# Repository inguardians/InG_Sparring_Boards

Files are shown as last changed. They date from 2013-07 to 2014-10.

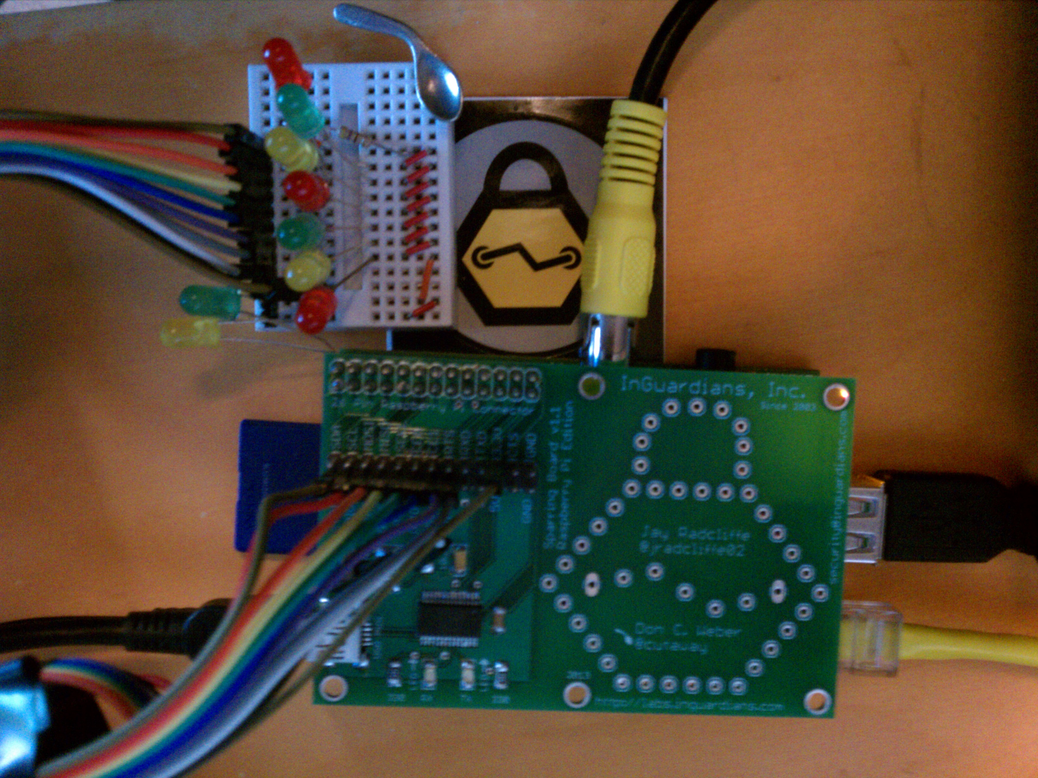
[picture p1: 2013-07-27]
trunk/version_1_pi/images/InG_version1_pi_led_testing_0.jpg

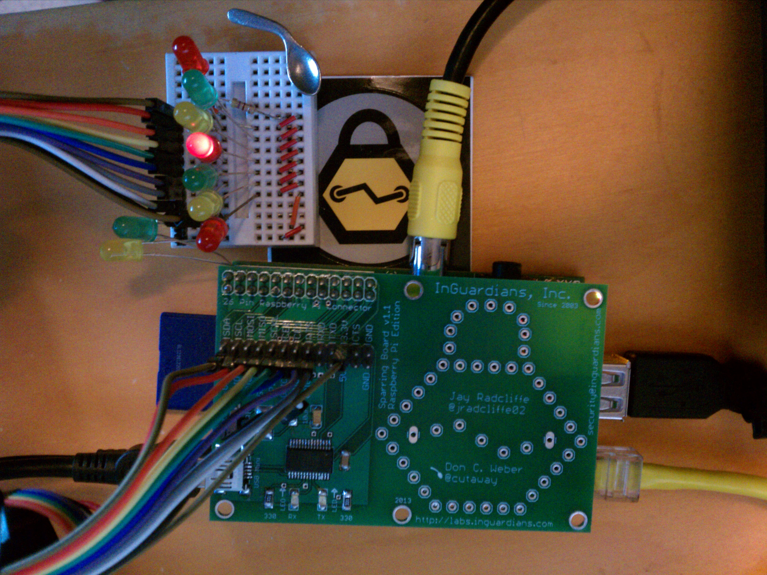
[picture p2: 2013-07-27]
trunk/version_1_pi/images/InG_version1_pi_led_testing_3.jpg

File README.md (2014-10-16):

InG_Sparring_Boards
===================

InGuardians Sparring Boards - a collection of printed circuit boards (PCB) to help users learn about embedded devices and the tools and techniques used during development and assessment.

InGuardians<br>
http://www.inguardians.com<br>
http://labs.inguardians.com<br>

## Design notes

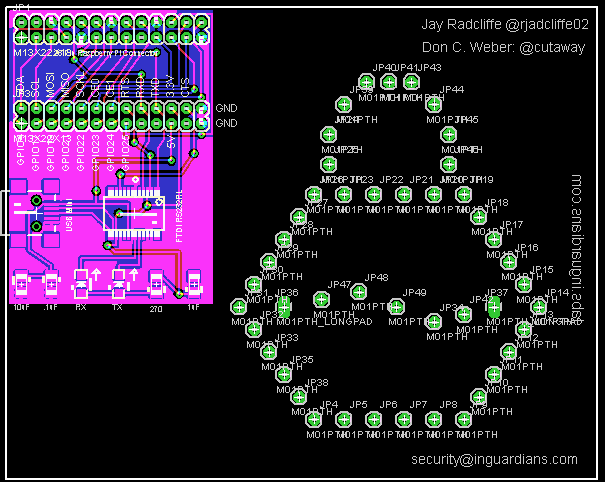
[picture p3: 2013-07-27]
trunk/version_1_pi/design/eagle/ing_dc2013_board.png

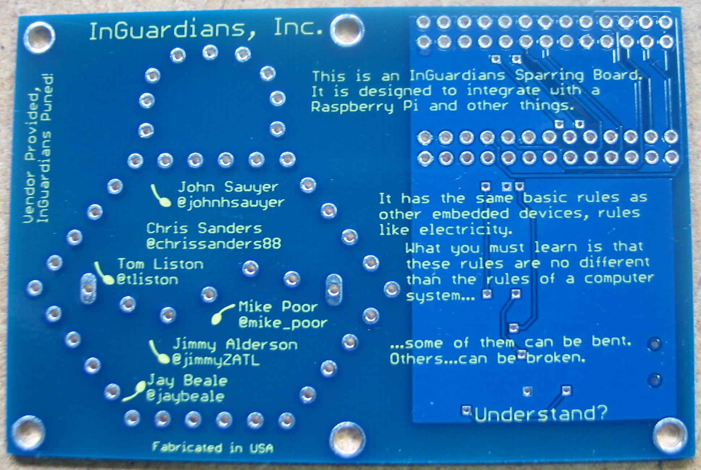
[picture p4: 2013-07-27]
trunk/version_1_pi/images/InG_version1_pi_back.JPG

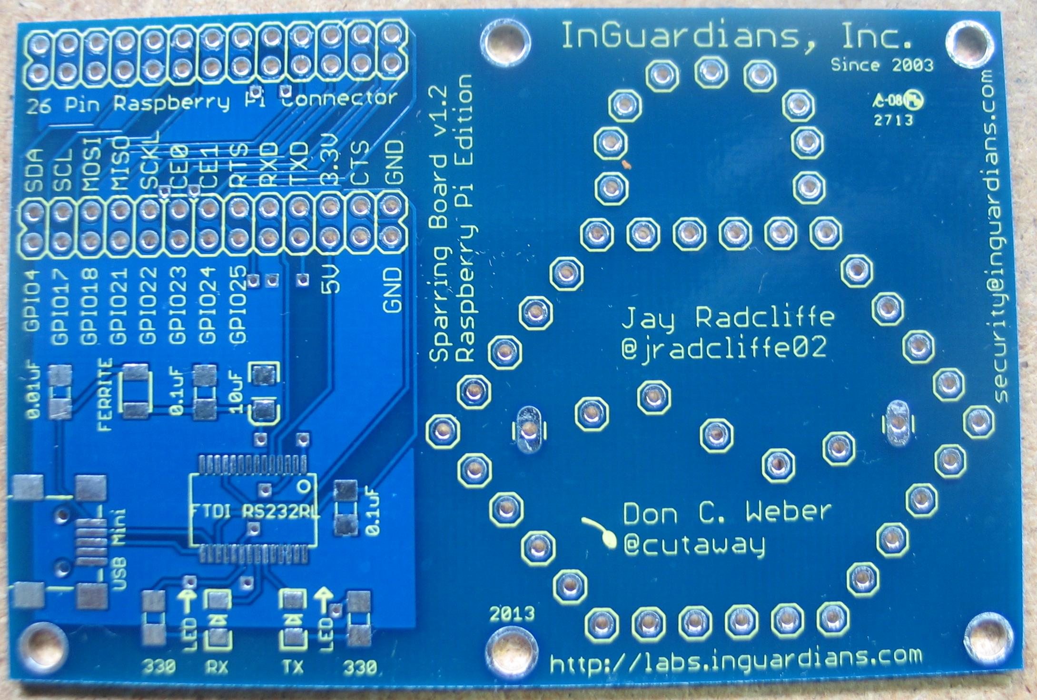
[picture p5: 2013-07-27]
trunk/version_1_pi/images/InG_version1_pi_front.JPG

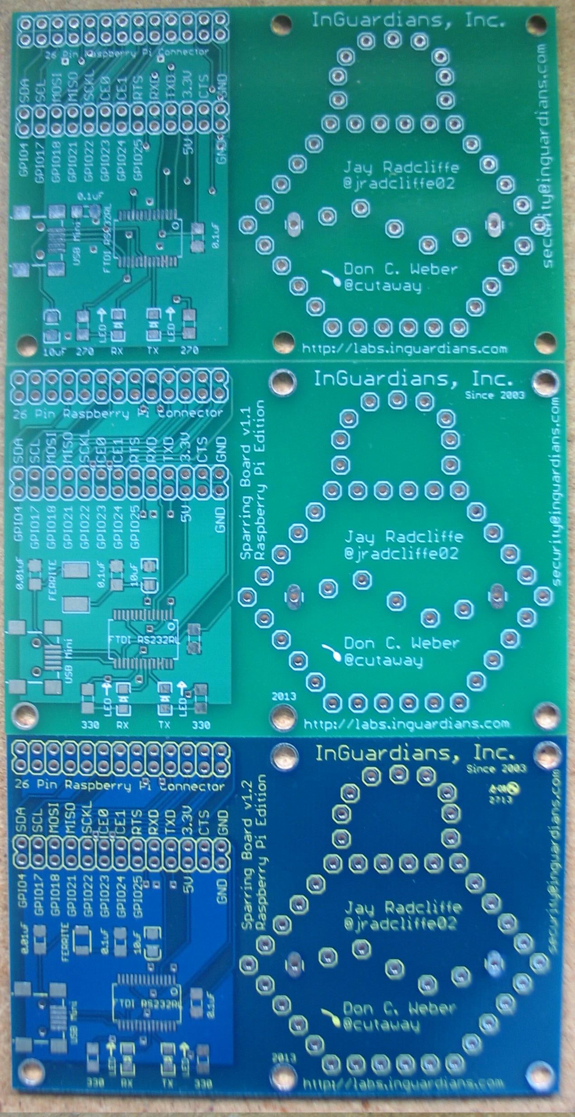
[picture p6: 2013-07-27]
trunk/version_1_pi/images/InG_version1_pi_progression_front.JPG

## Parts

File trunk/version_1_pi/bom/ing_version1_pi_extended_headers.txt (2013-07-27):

Extended Headers can be found on Adafruit:

http://www.adafruit.com/products/1112

Rubber bumper feet to help keep sparring board and 
Raspberry Pi separate.

http://www.adafruit.com/products/550

Last Date Checked: 20130727

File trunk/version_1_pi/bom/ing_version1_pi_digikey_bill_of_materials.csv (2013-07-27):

Digi-Key Part Number | Manufacturer | Manufacturer Part Number | Customer Reference | Quantity 1 | Quantity 2 | Quantity 3 | Description | Comments | RoHS Status | Lead Free Status | REACH Status
399-1249-1-ND | KEMET (VA) | C1206C104K5RACTU | C1 C2 | 2 | 0 | 0 | CAP CER 0.1UF 50V 10% X7R 1206 | Alternate Packaging Exists | RoHS Compliant | Lead free | Unaffected Jun-2012
P330ECT-ND | PANASONIC ELECTRONIC COMPONENTS (VA) | ERJ-8GEYJ331V | R1 R2 | 2 | 0 | 0 | RES 330 OHM 1/4W 5% 1206 SMD | Alternate Packaging Exists | RoHS Compliant | Lead free | Not Available
768-1007-1-ND | FTDI (VA) | FT232RL-REEL | U1 | 1 | 0 | 0 | IC USB FS SERIAL UART 28-SSOP | Alternate Packaging Exists | RoHS Compliant | Lead free | Unaffected Jun-2011
399-8268-1-ND | KEMET (VA) | T491A106K010AT7280 | C4 | 1 | 0 | 0 | CAP TANT 10UF 10V 10% 1206 | Alternate Packaging Exists | RoHS Compliant | Lead free | Unaffected Jun-2012
754-1174-1-ND | KINGBRIGHT COMPANY LLC (VA) | APTR3216SYCK | D1 | 1 | 0 | 0 | LED 3.2X1.6MM 590NM YLW CLR SMD | Alternate Packaging Exists | RoHS Compliant | Lead free | Unaffected Dec-2012
754-1439-1-ND | KINGBRIGHT COMPANY LLC (VA) | APT3216QBC/D | D2 | 1 | 0 | 0 | LED 3.2X1.6 470NM BL WTR CLR SMD | Alternate Packaging Exists | RoHS Compliant | Lead free | Unaffected Dec-2012
ED2992CT-ND | ON SHORE TECHNOLOGY INC (VA) | USB-M26FTR | JP2 | 1 | 0 | 0 | CONN USB MINI B R/A SMD | Alternate Packaging Exists | RoHS Compliant | Lead free | Unaffected Aug-2011
952-1918-ND | HARWIN INC | M20-9761346 | JP3 | 1 | 0 | 0 | 2X13POS DIL VERTICAL PIN HEADER |  | RoHS Compliant | Lead free | Not Available
587-3250-1-ND | TAIYO YUDEN (VA) | FBMH3216HM221NT | L1 | 1 | 0 | 0 | FERRITE BEAD 220 OHM 1206 | Alternate Packaging Exists | RoHS Compliant | Lead free | Not Available
399-1234-1-ND | KEMET (VA) | C1206C103K5RACTU | C3 | 1 | 0 | 0 | CAP CER 10000PF 50V 10% X7R 1206 | Alternate Packaging Exists | RoHS Compliant | Lead free | Unaffected Jun-2012

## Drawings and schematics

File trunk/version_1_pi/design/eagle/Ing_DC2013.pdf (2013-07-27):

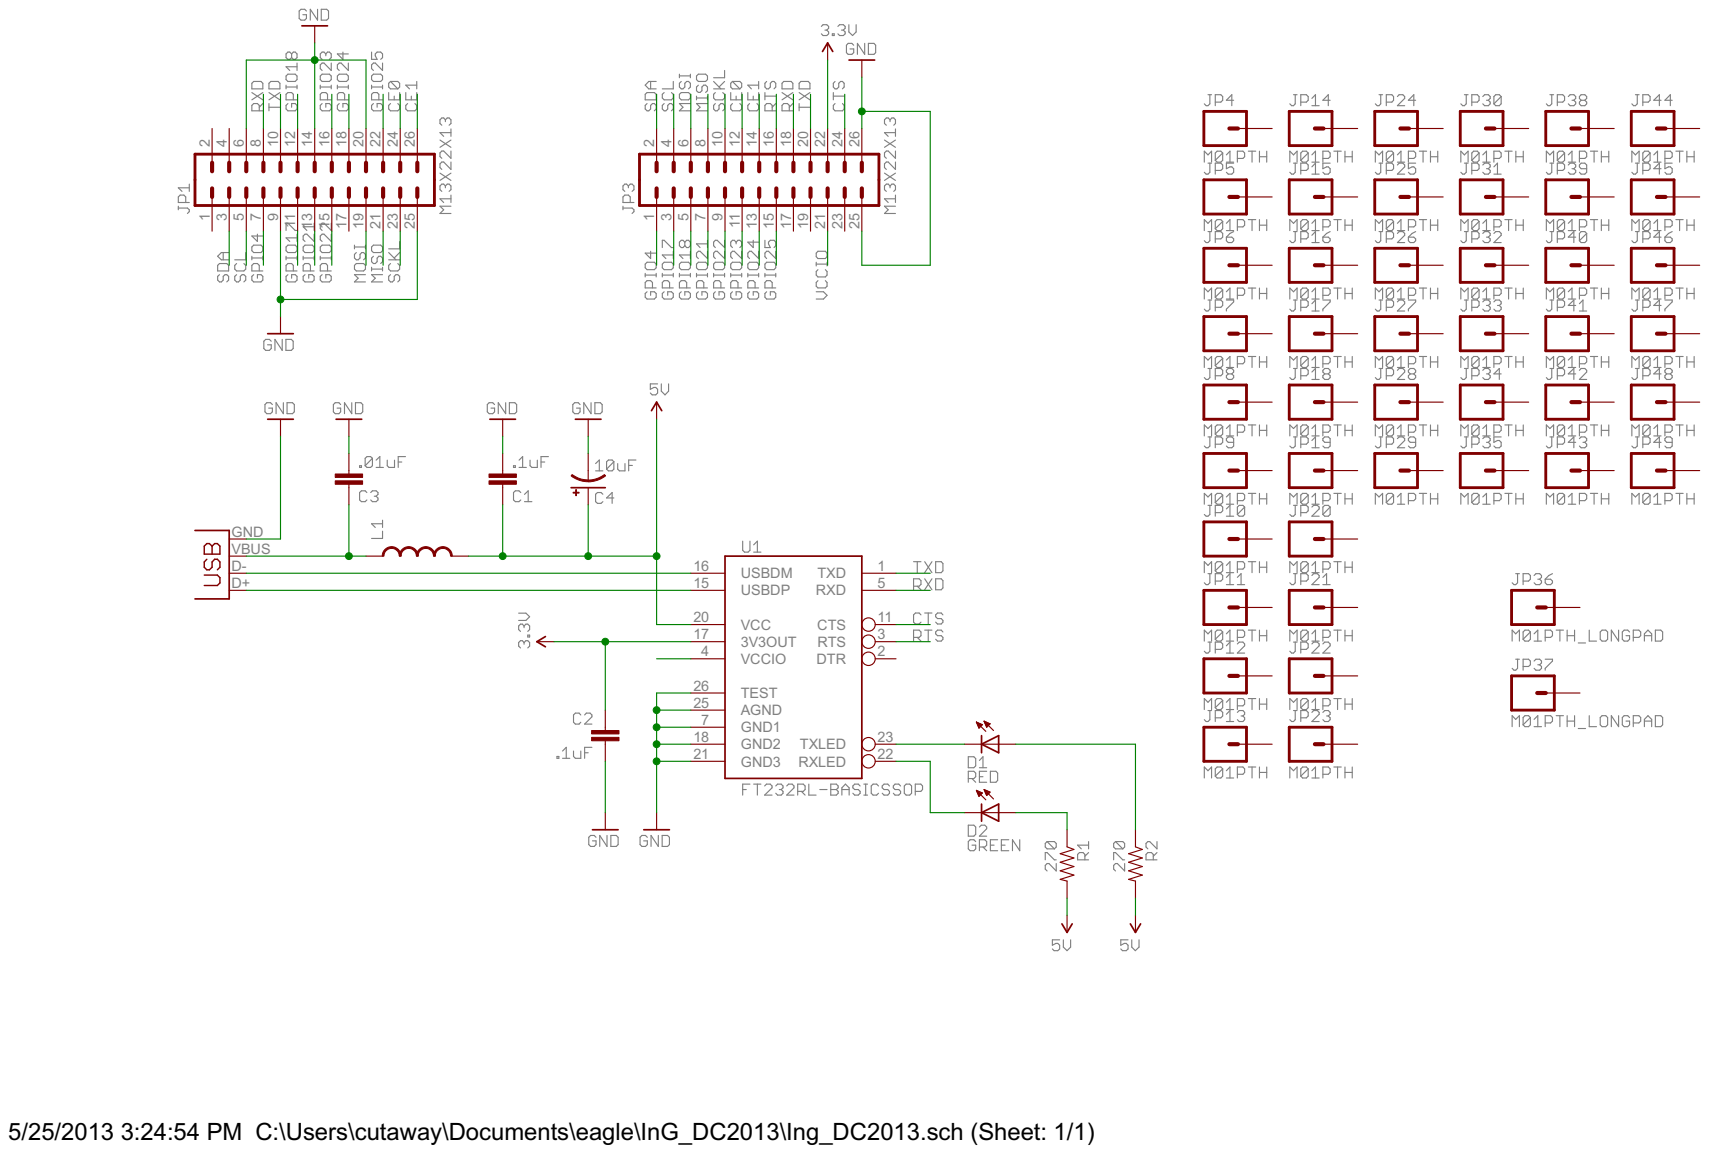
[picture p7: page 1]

5/25/2013 3:24:54 PM C:\Users\cutaway\Documents\eagle\InG_DC2013\Ing_DC2013.sch (Sheet: 1/1)

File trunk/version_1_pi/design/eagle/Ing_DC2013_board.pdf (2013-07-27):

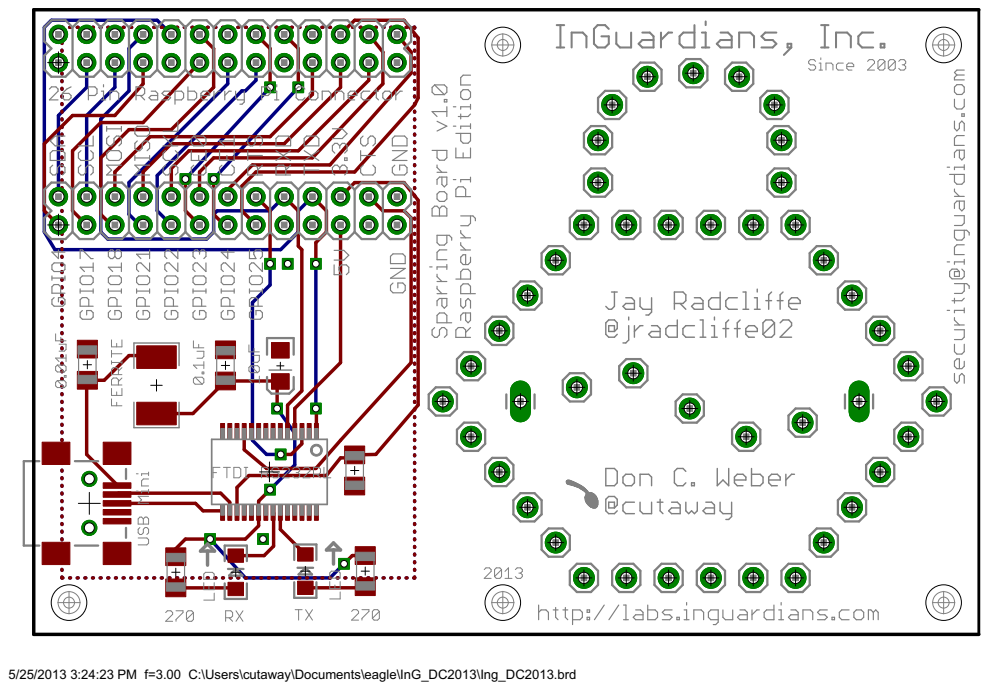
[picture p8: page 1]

5/25/2013 3:24:23 PM f=3.00 C:\Users\cutaway\Documents\eagle\InG_DC2013\Ing_DC2013.brd

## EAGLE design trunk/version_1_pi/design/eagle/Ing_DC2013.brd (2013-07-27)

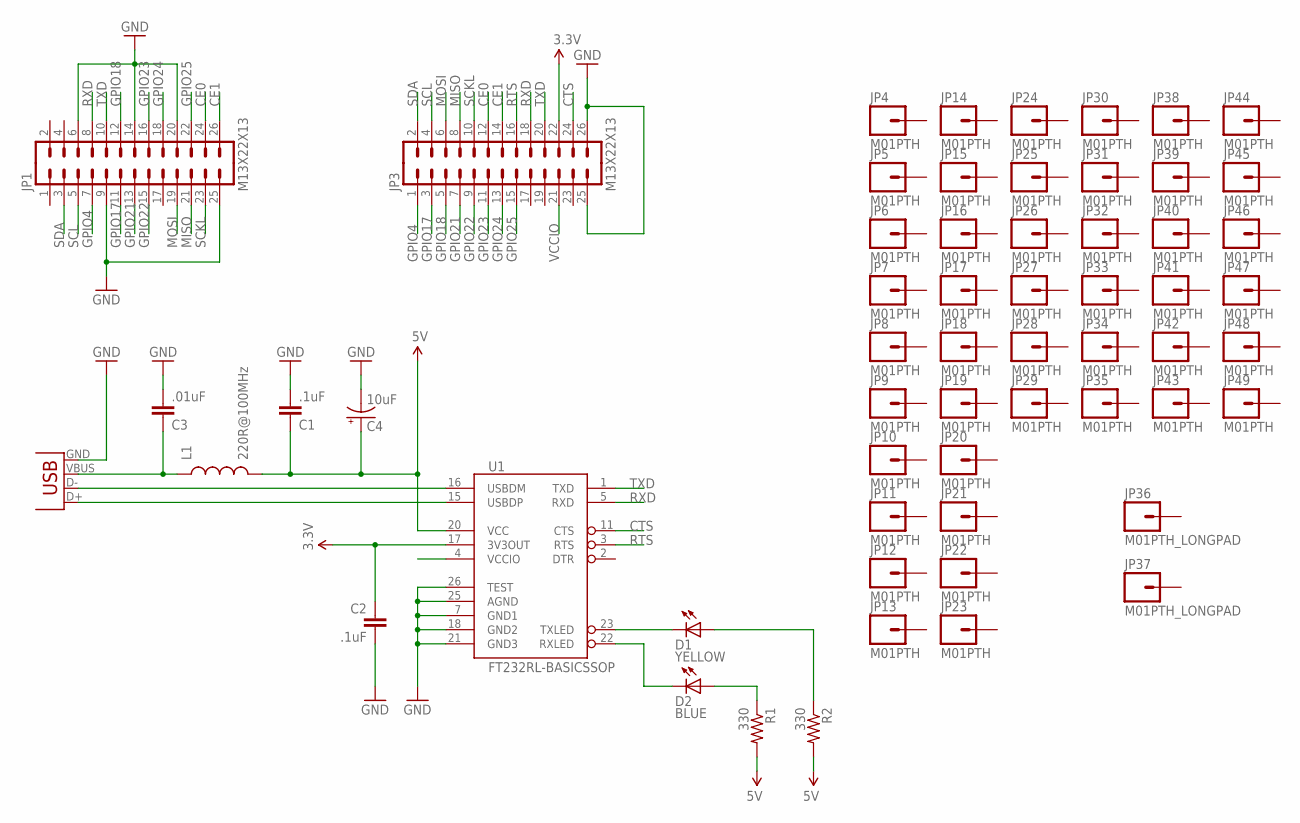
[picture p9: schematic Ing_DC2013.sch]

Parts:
C1, C2: .1uF; 1206
C3: .01uF; 1206
C4: 10uF; EIA3216
D1: YELLOW; LED-1206
D2: BLUE; LED-1206
JP1, JP3: M13X22X13; 2X13
JP2: USB-SMD-NS; USB-MINIB-NOSTOP
JP4, JP5, JP6, JP7, JP8, JP9, JP10, JP11, JP12, JP13, JP14, JP15, JP16, JP17, JP18, JP19, JP20, JP21, JP22, JP23, JP24, JP25, JP26, JP27, JP28, JP29, JP30, JP31, JP32, JP33, JP34, JP35, JP38, JP39, JP40, JP41, JP42, JP43, JP44, JP45, JP46, JP47, JP48, JP49: M01PTH; 1X01
JP36, JP37: M01PTH_LONGPAD; 1X01_LONGPAD
L1: 220R@100MHz; 1210
R1, R2: 330; 1206
U1: FT232RL-BASICSSOP; SSOP28DB

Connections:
3.3V: C2.1, JP3.22, U1.17 (3V3OUT)
5V: C1.1, C4.A (+), L1.2, R1.2, R2.2, U1.20 (VCC)
CE0: JP1.24, JP3.12
CE1: JP1.26, JP3.14
CTS: JP3.24, U1.11 (CTS)
GND: C1.2, C2.2, C3.2, C4.C (-), JP1.6, JP1.9, JP1.14, JP1.20, JP1.25, JP2.GND, JP3.25, JP3.26, U1.7 (GND1), U1.18 (GND2), U1.21 (GND3), U1.25 (AGND), U1.26 (TEST)
GPIO4: JP1.7, JP3.1
GPIO17: JP1.11, JP3.3
GPIO18: JP1.12, JP3.5
GPIO21: JP1.13, JP3.7
GPIO22: JP1.15, JP3.9
GPIO23: JP1.16, JP3.11
GPIO24: JP1.18, JP3.13
GPIO25: JP1.22, JP3.15
MISO: JP1.21, JP3.8
MOSI: JP1.19, JP3.6
unnamed: C3.1, JP2.VBUS, L1.1
unnamed: D2.A, R1.1
unnamed: D2.C, U1.22 (RXLED)
unnamed: D1.C, U1.23 (TXLED)
unnamed: JP2.D-, U1.16 (USBDM)
unnamed: JP2.D+, U1.15 (USBDP)
unnamed: D1.A, R2.1
RTS: JP3.16, U1.3 (RTS)
RXD: JP1.8, JP3.18, U1.5 (RXD)
SCKL: JP1.23, JP3.10
SCL: JP1.5, JP3.4
SDA: JP1.3, JP3.2
TXD: JP1.10, JP3.20, U1.1 (TXD)
VCCIO: JP3.21, U1.4 (VCCIO)

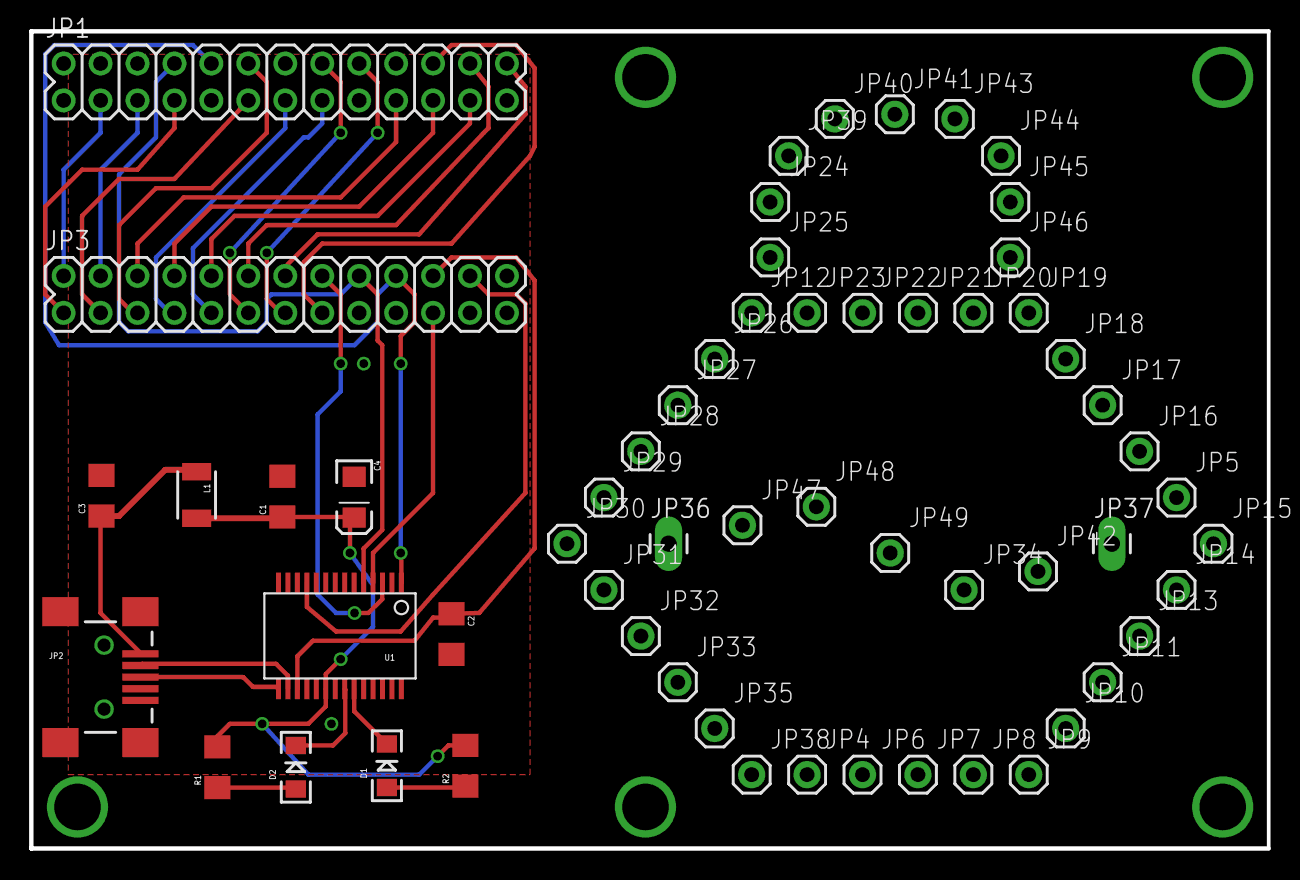
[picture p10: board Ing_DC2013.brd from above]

Board: 2 copper layers, 85.1 x 56.2 mm, 59 parts (0 on the bottom side), 30 nets.

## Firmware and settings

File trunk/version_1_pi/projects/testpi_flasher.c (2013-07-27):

###############################################
# Name: testpi_flasher.c
# Version: 0.1
# Company: InGuardians, Inc.
# Start Date: July 27, 2013
#
# Purpose:
#
#  This code is designed to turn on and off specific
#  Raspberry Pi GPIO pins as sent by a client. The serial
#  and GPIO setup components have been split out into 
#  header files.
#
# Developers: 
#   Cutaway (Don C. Weber)
#     The GPIO code is based on the example from Dom and Gert
#     on the Raspberry Pi website.
#
# Notes:
#  Compile on the Raspberry Pi using the following command:
#    gcc testpi_flasher.c -o testpi_flasher
#  If you are using a Raspberry Pi version one you may want to 
#  change the #define below or compile using the following:
#    gcc -DRPv1 testpi_flasher.c -o testpi_flasher
#
# Resources:
#   http://goodfet.sourceforge.net/
#   http://elinux.org/RPi_Low-level_peripherals
#
# TODO: 
#
# Change Log:
#
############################################

// Define Raspberry Pi version
#ifndef RPv1
#define RPv2
#endif

#include <stdio.h>
#include <stdlib.h>
#include <fcntl.h>
#include <sys/mman.h>
#include <unistd.h>

#include <stdint.h>

#include "include/pi.h"
#include "include/pi_serial.h"

int main(int argc, char **argv)
{
    short err = 0;
    short cnt = 0;
    short delay = 1;
    int qsec = 250000;
    #ifdef RPv1
    short pins[] = {4,17,18,21,22,23,24,25};    // Raspberry Pi v1 GPIO Pins
    #else
    short pins[] = {4,17,18,27,22,23,24,25};    // Raspberry Pi v2 GPIO Pins
    #endif
    short psize = sizeof(pins) / sizeof(short);
    uint8_t cmd = 0;

    // Set up serial
    printf("Setting serial.\n");
    err = pi_ser_init();
    if (err < 0){
        printf("Setting serial failed.\n");
        return -1;
    }

    // Set up gpi pointer for direct register access
    setup_io();
    printf("Serial setup successful.\n");

    /************************************************************************\
     * You are about to change the GPIO settings of your computer.          *
     * Mess this up and it will stop working!                               *
     * It might be a good idea to 'sync' before running this program        *
     * so at least you still have your code changes written to the SD-card! *
    \************************************************************************/
    // Set GPIO pins to output
    printf("Setting GPIO pins for output.\n");
    for (cnt=0;cnt<psize;cnt++) {
        INP_GPIO(pins[cnt]); // must use INP_GPIO before we can use OUT_GPIO
        OUT_GPIO(pins[cnt]);
    }

    // Turn OFF all LEDs
    printf("Setting GPIO pins to HIGH.\n");
    for (cnt=0;cnt<psize;cnt++) {
        GPIO_SET = 1<<pins[cnt];
        //GPIO_CLR = 1<<pins[cnt];
    }

    // Pause for effect
    usleep(qsec);

    // Roll through LEDs to show they work
    for (cnt=0;cnt<psize;cnt++) {
        printf("Setting GPIO pin %d to HIGH (CLR).\n",pins[cnt]);
        //GPIO_CLR = 1<<pins[cnt];
        //GPIO_LVL & (1<<pins[cnt]) ? (GPIO_CLR = 1<<pins[cnt]): (GPIO_SET = 1<<pins[cnt]);
        GPIO_TGL(pins[cnt])
        usleep(qsec);
        printf("Level: %s\n",(GPIO_LVL & (1<<pins[cnt]) ? "Low":"High"));
        printf("Setting GPIO pins %d to LOW (SET).\n",pins[cnt]);
        //GPIO_SET = 1<<pins[cnt];
        //GPIO_LVL & (1<<pins[cnt]) ? (GPIO_CLR = 1<<pins[cnt]): (GPIO_SET = 1<<pins[cnt]);
        GPIO_TGL(pins[cnt])
        usleep(qsec);
        printf("Level: %s\n",(GPIO_LVL & (1<<pins[cnt]) ? "Low":"High"));
    }
    printf("GPIO setup complete.\n");

    // Grab incoming
    //printf("incoming: 0x%x\n",serial_rx());

    printf("Start Main Loop.\n");
    // Grap first incoming command
    cmd = serial_rx();

    while (cmd != DONE){
        printf("incoming: 0x%x\n",cmd);
        switch (cmd){
            case ENTER :  // 0x0a //enter
                //Handle enter key which is used to flush incoming serial
                break;
            case FLASH4 :  // 0x61 //a
                printf("flashing: %d\n",PIPIN0);
                GPIO_CLR = 1<<PIPIN0;
                sleep(delay);
                GPIO_SET = 1<<PIPIN0;
                break;
            case FLASH17 : // 0x62 //b
                printf("flashing: %d\n",PIPIN1);
                GPIO_CLR = 1<<PIPIN1;
                sleep(delay);
                GPIO_SET = 1<<PIPIN1;
                break;
            case FLASH18 : // 0x63 //c
                printf("flashing: %d\n",PIPIN2);
                GPIO_CLR = 1<<PIPIN2;
                sleep(delay);
                GPIO_SET = 1<<PIPIN2;
                break;
            case FLASH27 : // 0x64 //d
                printf("flashing: %d\n",PIPIN3);
                GPIO_CLR = 1<<PIPIN3;
                sleep(delay);
                GPIO_SET = 1<<PIPIN3;
                break;
            case FLASH22 : // 0x65 //e
                printf("flashing: %d\n",PIPIN4);
                GPIO_CLR = 1<<PIPIN4;
                sleep(delay);
                GPIO_SET = 1<<PIPIN4;
                break;
            case FLASH23 : // 0x66 //f
                printf("flashing: %d\n",PIPIN5);
                GPIO_CLR = 1<<PIPIN5;
                sleep(delay);
                GPIO_SET = 1<<PIPIN5;
                break;
            case FLASH24 : // 0x67 //g
                printf("flashing: %d\n",PIPIN6);
                GPIO_CLR = 1<<PIPIN6;
                sleep(delay);
                GPIO_SET = 1<<PIPIN6;
                break;
            case FLASH25 : // 0x68 //h
                printf("flashing: %d\n",PIPIN7);
                GPIO_CLR = 1<<PIPIN7;
                sleep(delay);
                GPIO_SET = 1<<PIPIN7;
                break;
            default:
                printf("CMD not implemented.\n");
        }

        // Grap incoming command
        cmd = serial_rx();
    }

    printf("Done.\n");
    return 0;

} // main

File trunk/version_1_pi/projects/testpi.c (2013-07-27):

###############################################
# Name: testpi.c
# Version: 0.1
# Company: InGuardians, Inc.
# Start Date: July 27, 2013
#
# Purpose:
#
#  This code is designed to turn on and off all of the
#  Raspberry Pi GPIO pins.
#
# Developers: 
#   Cutaway (Don C. Weber)
#     The GPIO code is based on the example from Dom and Gert
#     on the Raspberry Pi website.
#
# Notes:
#  Compile on the Raspberry Pi using the following command:
#    gcc testpi.c -o testpi
#  If you are using a Raspberry Pi version one you may want to 
#  change the #define below or compile using the following:
#    gcc -DRPv1 testpi.c -o testpi
#
# Resources:
#   http://goodfet.sourceforge.net/
#   http://elinux.org/RPi_Low-level_peripherals
#
# TODO: 
#
# Change Log:
#
############################################

// Define Raspberry Pi version
//#define RPv1
#define RPv2

// Access from ARM Running Linux

#define BCM2708_PERI_BASE        0x20000000
#define GPIO_BASE                (BCM2708_PERI_BASE + 0x200000) /* GPIO controller */


#include <stdio.h>
#include <stdlib.h>
#include <fcntl.h>
#include <sys/mman.h>
#include <unistd.h>

#define PAGE_SIZE (4*1024)
#define BLOCK_SIZE (4*1024)

int  mem_fd;
void *gpio_map;

// I/O access
volatile unsigned *gpio;

// GPIO setup macros. Always use INP_GPIO(x) before using OUT_GPIO(x) or SET_GPIO_ALT(x,y)
#define INP_GPIO(g) *(gpio+((g)/10)) &= ~(7<<(((g)%10)*3))
#define OUT_GPIO(g) *(gpio+((g)/10)) |=  (1<<(((g)%10)*3))
#define SET_GPIO_ALT(g,a) *(gpio+(((g)/10))) |= (((a)<=3?(a)+4:(a)==4?3:2)<<(((g)%10)*3))

#define GPIO_SET *(gpio+7)  // sets   bits which are 1 ignores bits which are 0
#define GPIO_CLR *(gpio+10) // clears bits which are 1 ignores bits which are 0

void setup_io();

int main(int argc, char **argv)
{
    short iter = 0;
    short miter = 5;
    short cnt = 0;
    short delay = 1;
    #ifdef RPv1
    short pins[] = {4,17,18,21,22,23,24,25};    // Raspberry Pi v1 GPIO Pins
    #else
    short pins[] = {4,17,18,27,22,23,24,25};    // Raspberry Pi v2 GPIO Pins
    #endif
    short psize = sizeof(pins) / sizeof(short);

    // Set up gpi pointer for direct register access
    setup_io();

    /************************************************************************\
     * You are about to change the GPIO settings of your computer.          *
     * Mess this up and it will stop working!                               *
     * It might be a good idea to 'sync' before running this program        *
     * so at least you still have your code changes written to the SD-card! *
    \************************************************************************/
    // Set GPIO pins to output
    printf("Setting GPIO pins for output.\n");
    for (cnt=0;cnt<psize;cnt++) {
        INP_GPIO(pins[cnt]); // must use INP_GPIO before we can use OUT_GPIO
        OUT_GPIO(pins[cnt]);
    }

    // Turn off all LEDs
    printf("Setting GPIO pins to LOW.\n");
    for (cnt=0;cnt<psize;cnt++) {
        GPIO_SET = 1<<pins[cnt];
        //GPIO_CLR = 1<<pins[cnt];
    }

    // Pause for effect
    sleep(delay);

    while (iter < miter){
        for (cnt=0;cnt<psize;cnt++) {
            printf("Setting GPIO pin %d to HIGH (CLR).\n",pins[cnt]);
            GPIO_CLR = 1<<pins[cnt];
            sleep(delay);
            printf("Setting GPIO pins %d to LOW (SET).\n",pins[cnt]);
            GPIO_SET = 1<<pins[cnt];
            sleep(delay);
        }
        iter++;
    }

    return 0;

} // main

//
// Set up a memory regions to access GPIO
//
void setup_io()
{
     /* open /dev/mem */
     if ((mem_fd = open("/dev/mem", O_RDWR|O_SYNC) ) < 0) {
          printf("can't open /dev/mem \n");
          exit(-1);
     }

   /* mmap GPIO */
     gpio_map = mmap(
          NULL,             //Any adddress in our space will do
          BLOCK_SIZE,       //Map length
          PROT_READ|PROT_WRITE,// Enable reading & writting to mapped memory
          MAP_SHARED,       //Shared with other processes
          mem_fd,           //File to map
          GPIO_BASE         //Offset to GPIO peripheral
     );

     close(mem_fd); //No need to keep mem_fd open after mmap

     if (gpio_map == MAP_FAILED) {
          printf("mmap error %d\n", (int)gpio_map);//errno also set!
          exit(-1);
     }

     // Always use volatile pointer!
     gpio = (volatile unsigned *)gpio_map;

} // setup_io

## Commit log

2013-07-27 cutaway - initial commit with Sparring Board v1.2
    [Ing_DC2013.brd, Ing_DC2013.sch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]
2013-07-27 cutaway - added images
    [ing_version1_pi_digikey_bill_of_materials.csv]

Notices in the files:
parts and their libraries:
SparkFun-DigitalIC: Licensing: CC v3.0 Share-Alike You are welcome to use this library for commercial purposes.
